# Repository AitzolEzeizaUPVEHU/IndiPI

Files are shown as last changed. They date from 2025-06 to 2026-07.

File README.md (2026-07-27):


# IndiPI
Laboratory kit for Industrial Information Technology based on Raspberry PI 5

## Description
A hands-on educational platform for learning industrial IoT and automation using Raspberry Pi 5.

## Getting Started
The Gerber files are available for creating your own kit. You would need the BOM described, an ADS analog-to-digital converter and a Raspberry PI 5. You can check the figures in order to know how to mount the whole kit.

## Authors
- Imanol Bardaji Zuriarrain
- Aitzol Ezeiza Ramos
- Kauldi Odriozola Ieregi

## License
CC-SA-4.0

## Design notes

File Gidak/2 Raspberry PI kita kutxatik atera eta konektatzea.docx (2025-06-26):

# Raspberry PI kita kutxatik atera eta konektatzea

## Sarrera

Esan bezala, Sistemen ingeniaritza eta Automatika saileko Raspberry PI kitarekin lan egiteko gure laborategietako PCetan software guztia instalatuta aurkituko duzu. Elikatu eta Ethernet kablea ongi konektatzea nahikoa da urrunetik konektatu eta lanean hasteko.

Etxean ere modu berean lan egin nahiko bazenu, gida honek pausoz pauso erakutsiko dizu nola instalatu Ethernet-USB moldagailua Raspberry Piarekin komunikatzeko.

Bi modu ikusiko dugu, bata eskuzkoa, bestea automatikoa. Gure laborategikoa ez den PC batean lan egiteko batzuetan konfigurazio ezberdinak aurkitu ditzakegunez, lehenik eskuzko modua ikusiko dugu eta, horren arabera, agian aldaketa txikiren bat egin beharko diogu tresna automatikoari zure kasuan funtzionatzeko. Aurrera ba!

## Gure kitaren “unboxing”

Gure kitak plaka nagusi bat dauka eta bertan Raspberry Pia jarrita dago, erabiltzeko prest. Funtzionatzeko, ezinbestekoa da elikatzea. Elikatzeko, USB-C kargagailu bat erabiltzen dugu. Edozeinek balio du, baina kitarekin erabiltzen duguna 27 W-ekoa da. Potentzia horrekin, plakak bere ahalmen osoan lan egin dezake. Beraz, lehenengo gauza egin behar duguna elikatzea da (beno, ordenak ez du eragin handirik izango). Ikus 1. Irudia konexioa ikusteko.

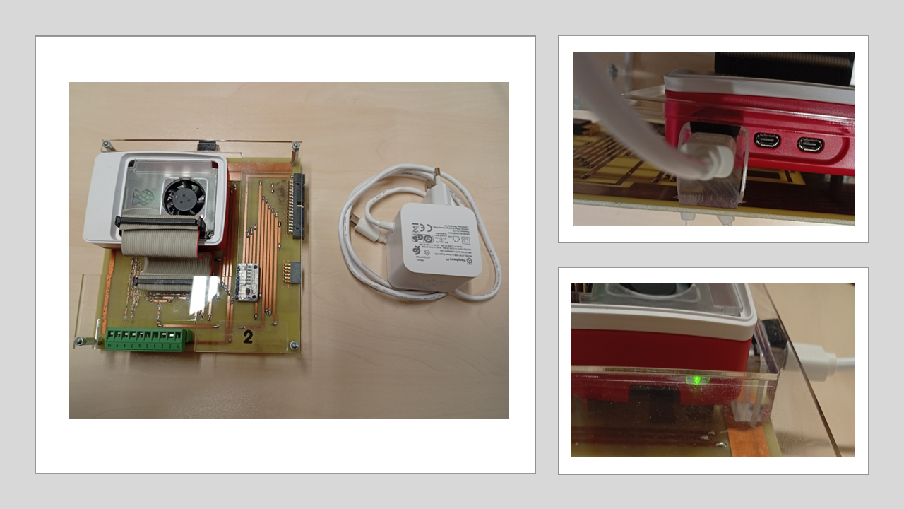
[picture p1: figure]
Raspberry PI kita bere kargagailuarekin.

1. Irudia: Raspberry PI kita bere kargagailuarekin.

Bestalde, Raspberry Piak inora konektatu gabe lan egin badezake ere, gure kasuan PCtik lan egin nahi dugu. Horretarako, Ethernet sarea erabiliko dugu. Gure kasuan, gure laborategiko PCek ez dute WiFirik, beraz, aukera bakarra zen. Etxean WiFia erabil daiteke, baina Raspberry Piaren WiFiak nahiko historia beltza du (gu, behintzat, ez gara gehiegi fidatzen bere WiFiaz). Raspberry Piak RJ45 konektore bat dauka Etherneterako. Guk Ethernet USB moldagailu bat erabiltzen dugu PCra (edo eramangarrira) konektatzeko. 2. Irudian ikus dezakezu nola konektatzen dugun.

Raspberry Piaren kutxan osagai gehiago aurkituko dituzu, baina horiek aurreragorako utziko ditugu. Presarik ez.

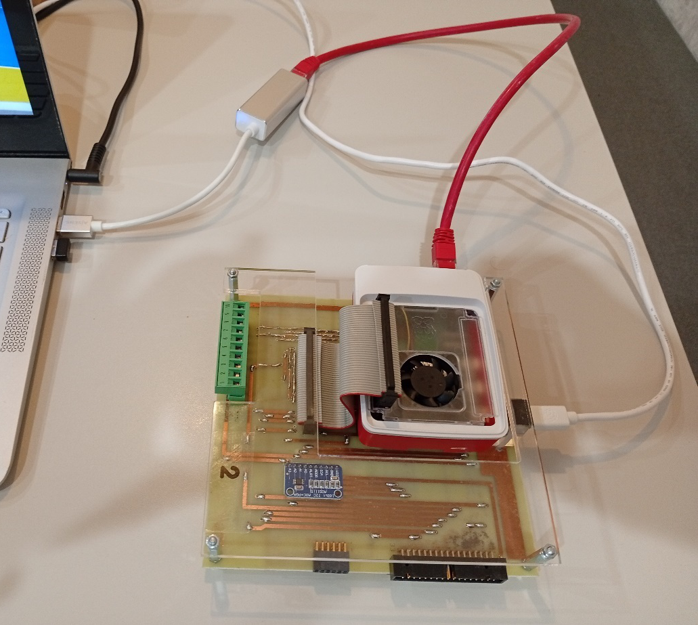
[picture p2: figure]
Raspberry PI Kita elikatuta eta USB moldagailuaren bitartez eramangarrira konektatuta.

2. Irudia: Raspberry PI Kita elikatuta eta USB moldagailuaren bitartez eramangarrira konektatuta.

## Ethernet sarea eskuz konfiguratzen

Windowsen guk erabiltzen dugun Realtek Ethernet USB Gigabit moldagailua automatikoki ezagutzen du. Zoritxarrez, pittin bat latosoa da berarekin lan egitea ez bada ongi konfiguratzen. Guk, gainera, Interneterako sarbidea eman nahi diogu Raspberry Piari gure PCaren bitartez. Interneterako sarbidea zuzenean WiFi bitartez eman daiteke, baina aipatu dugu gure laborategietan zailtasunak ditugula WiFiarekin lan egiteko eta, gainera, Raspberry Piaren WiFia ez da orain arte oso fidagarria izan. Zer egin orduan?

Windowsek Internet Connection Sharing (ICS) izeneko zerbitzu bat dauka, Internetera konektatzeko erabiltzen dugun moldagailuak beste moldagailu bati Interneterako sarbidea emateko. Zerbitzu honekin asko borrokatu behar izan dugu, baina funtzionatzen du ongi konfiguratuz gero. Modu automatikoa gaitzeko aurrerago aipatuko ditugu zailtasunak, baina oraingoz eskuz ongi konfiguratzen saiatuko gara.

Windows 10en, sareen konfigurazioa irekitzeko kontrol paneletik sartu behar dugu (hizkuntzaren arabera ezberdina da (niri adibidez, “Kontrol-panela\Sarea eta Internet\Conexiones de red” agertzen zait, euskara eta gaztelania nahastuz). Edozein hizkuntzatan erraz aurkitzeko modurik onena komando lerroa edo “Exekutatu” leihoa erabiltzea da.

1. Sakatu Win + R teklatuan, "Exekutatu" leihoa irekiko da. Idatzi komando hau eta sakatu Sartu.

control ncpa.cpl

2. Sarea eta partekatzeko zentroa irekitzen da (ikus 3. Irudia).

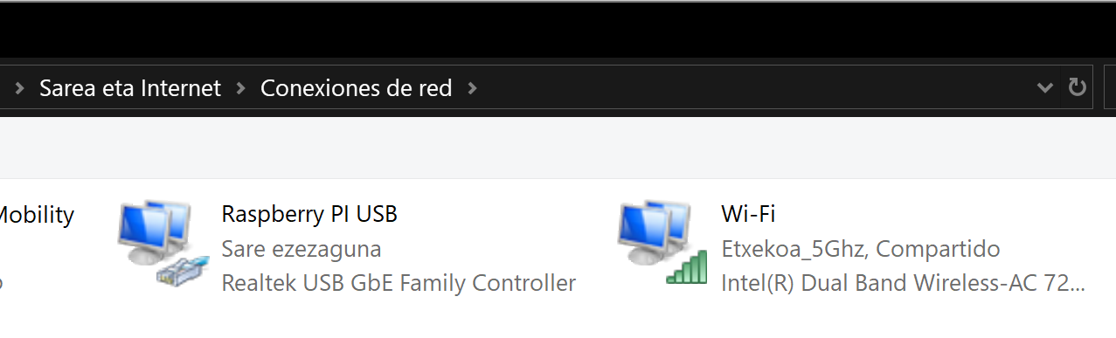
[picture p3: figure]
Sare konexioen kontrol panela.

3. Irudia: Sare konexioen kontrol panela.

3. Internetera sarbidea duen sarea identifikatu. “Ethernet n” izeneko gailu bat ikusten baduzu, begiratu ea Raspberry Pia konektatzeko moldagailua den. Fisikoki deskonektatu eta konektatu egin dezakezu, ikusteko hori dela. Nahi baduzu, izena alda iezaiozu irudian egin dugun bezala, hobeto identifikatzeko.
4. Batzuetan, gailu gehiago izango ditugu, hardwarezkoak edo birtualak. Ez da ezer gertatzen, soilik fijatu zaitez ea horietako baten batek deskribapenean USB edo antzerako zerbait daukan. Automatizatzeko garrantzitsua izan daiteke.
5. Internet eskaintzen duen moldagailua etxeko PC batean Wi-Fi moldagailua izango da ziurrenik. Bere menua ireki dezakezu klik bikoitza eginez. Bertan Propietateak ireki eta “Uso Compartido” atalera joan. Bertan partekatzea aktibatu eta, bi moldagailu baino gehiago badaukazu, Raspberry Piaren moldagailua aukeratu zerrendatik. Gogoratu hau dena Raspberry Pia konektatuta egitea komeni dela (4. Irudia).

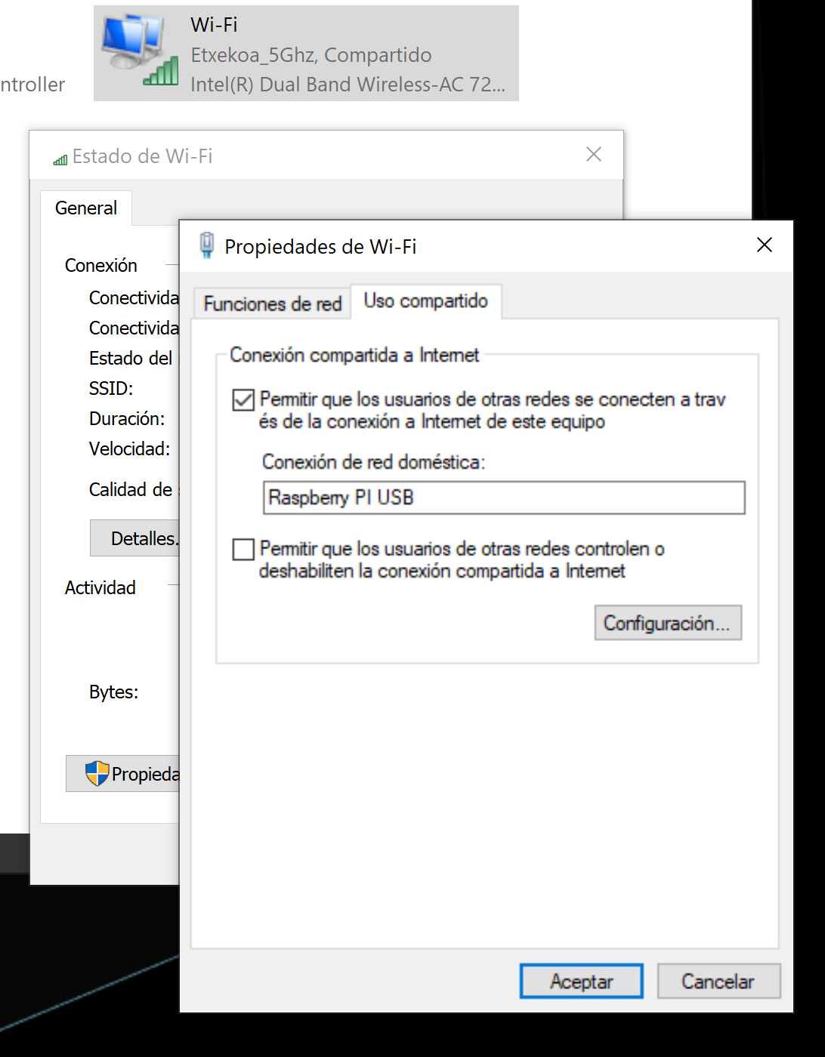
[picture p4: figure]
“Uso Compartido” leihoan egin behar den konfigurazioa.

4. Irudia: “Uso Compartido” leihoan egin behar den konfigurazioa.

6. Behin aktibatuta, zoritxarrez ez du beti funtzionatzen. Gehienetan Raspberry Piaren moldagailua desaktibatu behar da eta berriz aktibatu. Hau oso erraz egiten da “Conexiones de Red” panel horretatik. Hau egitean, IP helbide dinamiko bat esleituko zaio Raspberry Piari eta izen berdina emango zaio beti: raspberrypi.mshome.net (mshome.net atzizkiak sare lokal partekatua adierazten du Windowsen).
7. Amaitzeko, ondo funtzionatzen duen probatuko dugu. Modu errazena TigerVNC erabiltzea da (ikus 5. Irudia). TigerVNC ireki eta x. irudian agertzen den izena jarri. Erabiltzailea eskatzen dizunean, ”pi” jarri eta pasahitza “automatika2024”.

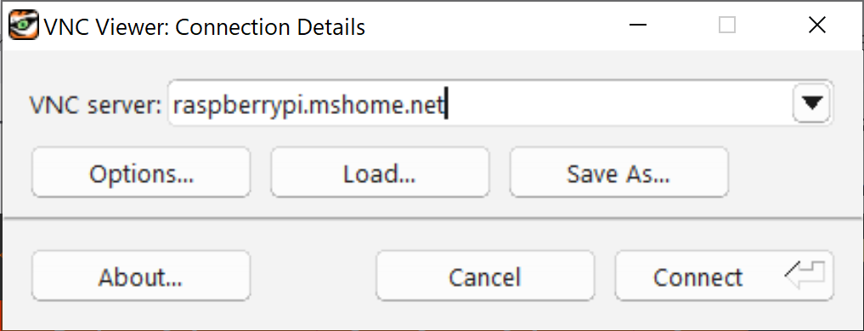
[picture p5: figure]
Tiger VNC konektatzeko prest

5. Irudia: Tiger VNC konektatzeko prest.

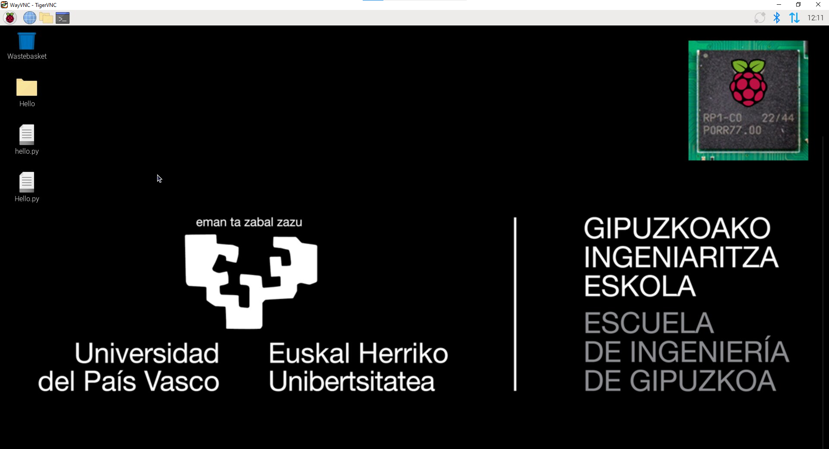
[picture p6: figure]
Raspberry PIaren mahaigaina, TigerVNCtik ikusita.

6. Irudia: Raspberry PIaren mahaigaina, TigerVNCtik ikusita.

Dena ondo badoa, 6. Irudia ikusiko dugu. Zorionak! Errazagoa da esatea egitea baino.

Badago trikimailu aurreratu bat erabiltzailea eta pasahitza ez sartu behar izateko TigerVNC. Aurrerago, berdina egingo dugu VS Coden. PowerShellen agindu hauek funtzionatzen dute:

[System.Environment]::SetEnvironmentVariable('VNC_USERNAME', 'pi', [System.EnvironmentVariableTarget]::User)

[System.Environment]::SetEnvironmentVariable('VNC_PASSWORD', 'xxxxxxxxxxxx', [System.EnvironmentVariableTarget]::User)

## Ethernet sarea modu automatikoan konfiguratzeko scripta

Automatikoki martxan jartzeko aukera guretzat oso interesgarria da. Batetik, eskuz egindako pausoak behin eta berriz egitea aspergarria da. Bestetik, kit ezberdinak PC berdinean erabiliz gero, moldagailua izen ezberdinarekin detektatzen ditu eta pauso guztiak errepikatzeko beharrean gaude. Modu automatikoa aktibatzeko hiru pauso eman behar ditugu.

1. Behar ditugun tresna batzuk instalatu batch script bat erabiliz
2. Konfiguratzeko PowerShell scripta instalatu eta probatu.
3. Ataza programatu bat sortu automatikoki moldagailua konektatzean gure scripta aktibatzeko.

Bide batez, oso interesgarria da gaur egungo ingeniarientzat komando lerroa erabiltzen ikastea eta PowerShell eta antzerako scriptak erabiltzen jakitea. Guk modu gidatuan egingo dugu eta dena prest dago, baina interesgarria da horrelako tresnak ezagutzea.

### 1. Instalazio scripta (SetupRPIKit2025.bat)

Karpeta berean (berdin du non) gorde SetupRPIKit2025.bat, resetICS.ps1 eta resetICS.log.

Karpeta horretara joan eta eskuineko botoiarekin ireki SetupRPIKit2025.bat eta “Exekutatu Administratzaile gisa” aukeratu. Normalean, etxeko PC batean gure erabiltzaile arruntak administratzaile pribilejioak dauzka, baina pribilejiorik gabe lan egiten du ez badiogu kontrakoa esaten (ikus 7. Irudia).

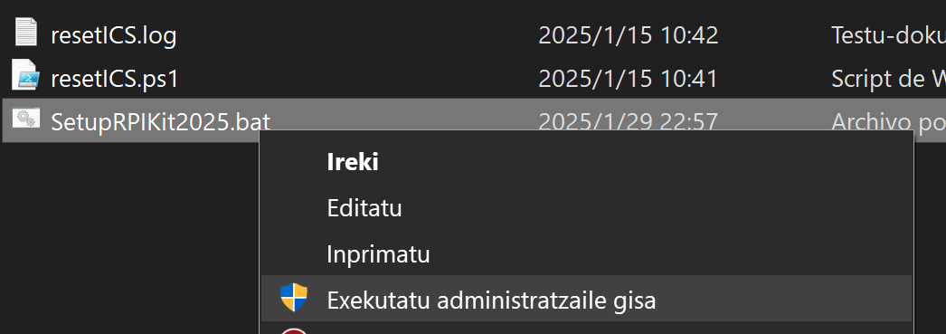
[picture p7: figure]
“Exekutatu Administratzaile gisa” aukera testuinguru menuan

7. Irudia: “Exekutatu Administratzaile gisa” aukera testuinguru menuan

Ongi funtzionatzen badu, C:\Program Files\Scripts karpeta bat sortuko da eta bertara eskuz resetICS.ps1 scripta eta resetICS.log fitxategiak kopiatu behar ditugu.

### 2. PowerShell script nagusia (resetICS.ps1)

Kasu honetan PowerShell script bat exekutatuko dugu, aurrekoa bezala. PowerShell erabiliko dugu, gainera, dena ongi dagoela ikusteko. Ireki PowerShell administratzaile gisa (eskuineko botoiarekin egin dezakezu) eta ondorengo lerroa proba ezazu:

ssh pi@raspberrypi.mshome.net

Agindu honek funtzionatzen badu, pasahitza sartzeko eskatuko dizu (automatika2024) eta dena ongi dago. Segidan, gure scripta ongi dabilen ala ez probatu nahi dugu. Horretarako, Internet Konexioa Partekatzea (ICS) desktibatuko dugu eta ongi desaktibatu den ziurtatu:

disable-ics

eta berriz probatu ssh agindua:

ssh pi@raspberrypi.mshome.net

Orain bai, errorea eman beharko lizuke, hau da, ez luke erantzun behar. Hau gertatzen denean, ez da denbora asko itxaron behar gaizki doala ikusteko. Ctrl+C sakatu prozesuaren iraupena mozteko.

Orain resetICS.ps1 scripta probatuko dugu eta segundo batzuk itxaron berriz saiatu baino lehen. resetICS.ps1 aginduak berak nahita dexente itxaroten du. Ez izan presarik eta amaitzea itxaron ezazu. PowerShell komandoetan itxarotearena Sleep aginduarekin egiten da eta guk geuk ere pausak sar ditzakegu komando lerrotik.

cd “c:\Program Files\Scripts”

resetICS.ps1

Sleep 2

ssh pi@raspberrypi.mshome.net

Bide batez, arrakasta baduzu, Linux sistema eragilearen komando lerroan sartu zara. Zorionak! Oso seinale ona da! Bertatik atera nahi baduzu, “exit” idatzi eta enter saka ezazu. Disable-ScheduledTask errore batzuk ematen badizkizu, lasai, hori fase honetan normala delako. resetICS.ps1 scriptak segundo batzuk beharko ditu, pazientzia izan.

Scripta martxan jarri eta berehala segurtasun ohar bat jasotzen baduzu, hori ere normala da (ikus 8. irudia). “Z” sar ezazu scriptari martxan jartzeko baimena emateko eta lixto.

8. Irudia: Segurtasun oharra PowerShell scripta exekutatzean.

Dena ongi badoa, 9. irudikoaren antzerako zerbait aterako zaizu:

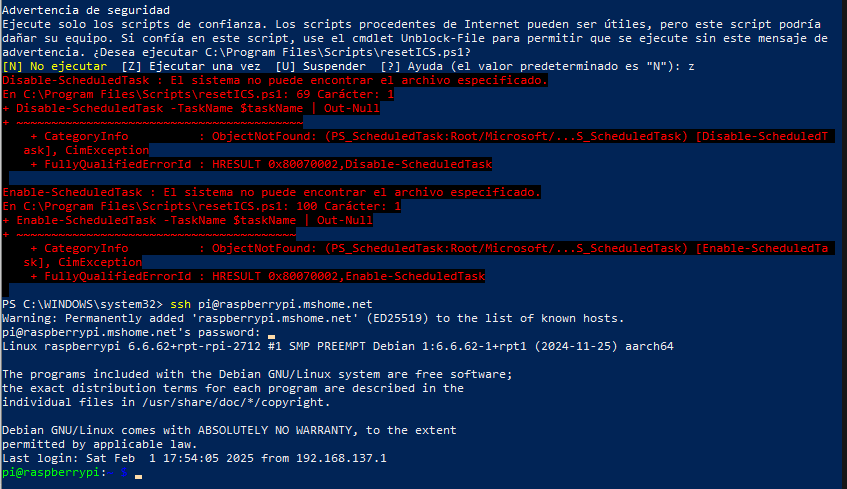
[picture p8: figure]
resetICS.ps1 scripta arrakastaz martxan.

9. Irudia: resetICS.ps1 scripta arrakastaz martxan.

### 3. Ataza Programatua sortzea (RaspberryPIConnect.xml)

Amaitzeko, Ataza Programatzailea (Task Scheduler, Programador de Tareas) erabiliko dugu gure USB portuan moldagailua sartzen dugun bakoitzean gure scripta martxan jartzeko. Hau ere oso interesgarria da berez! Ba al zenekien atazak programatu zitezkeela?

“Programador de Tareas delako bila ezazu Windowseko barran edo, lehen bezala, Windows + R erabili eta hau idatz ezazu:

control schedtasks

Irekiko den tresna oso interesgarria eta aukera ugari ditu. Guk dena prest daukagu dagoeneko, beraz, xehetasun guztiak sartu ordez, prest daukagun ataza inportatuko dugu Acción > Import Task… eginez. (ikus 8. Irudia).

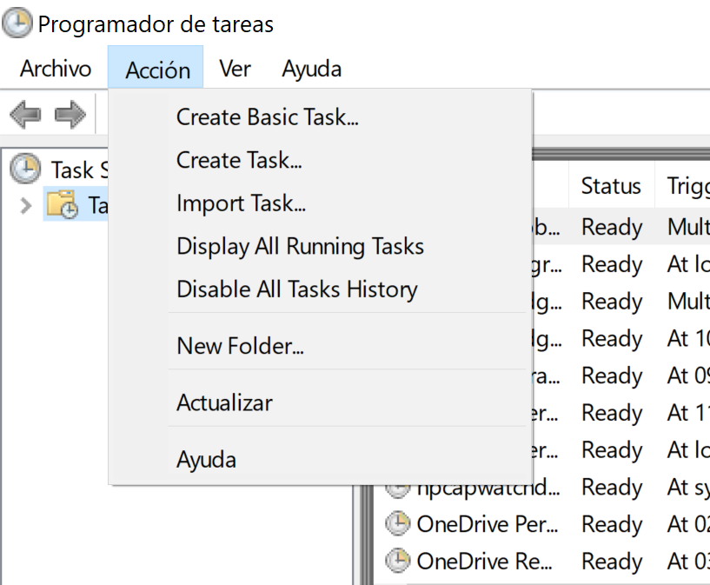
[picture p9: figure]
“Programador de tareas” delakoa. Bertatik “Import Task…” egingo dugu.

10. Irudia: “Programador de tareas” delakoa. Bertatik “Import Task…” egingo dugu.

Hortik aukera ezazu RaspberryPIConnect.xml izeneko fitxategia. Orduan 9. Irudikoaren antzerako agertuko zaizu. Kuriosoa da nola hizkuntzak nahastuta ageri diren. Euskarazko sistemen kasuan, euskara, gaztelania eta ingelesa ager daitezke aldi berean, erokeria da.

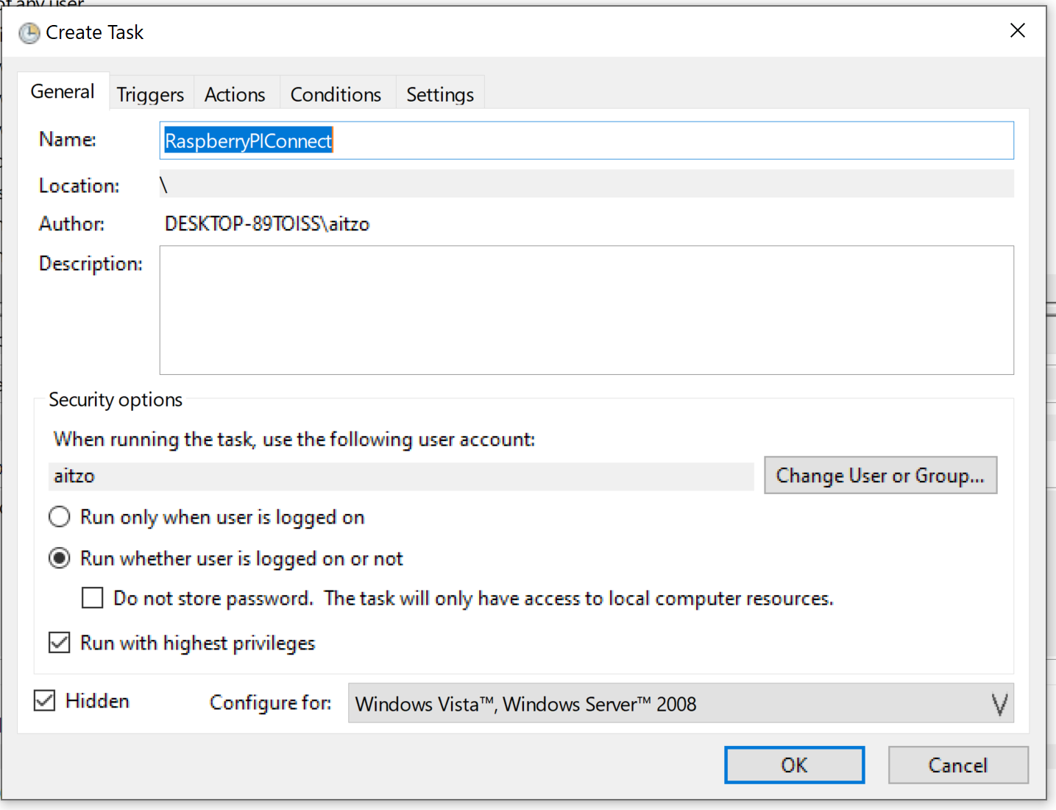
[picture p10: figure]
Create Task leihoa. Bertan ataza programatuaren xehetasunak daude.

11. Irudia: Create Task leihoa. Bertan ataza programatuaren xehetasunak daude.

Oraindik ez dago dena prest, “Change User or Group” botoia sakatu behar delako eta leiho horretan (10. Irudia) zure PCko erabiltzaile izena idatzi eta bilatu beharko duzu. Ez bazaude ziur zein den, zure komando lerroan agindu hau sartu:

whoami

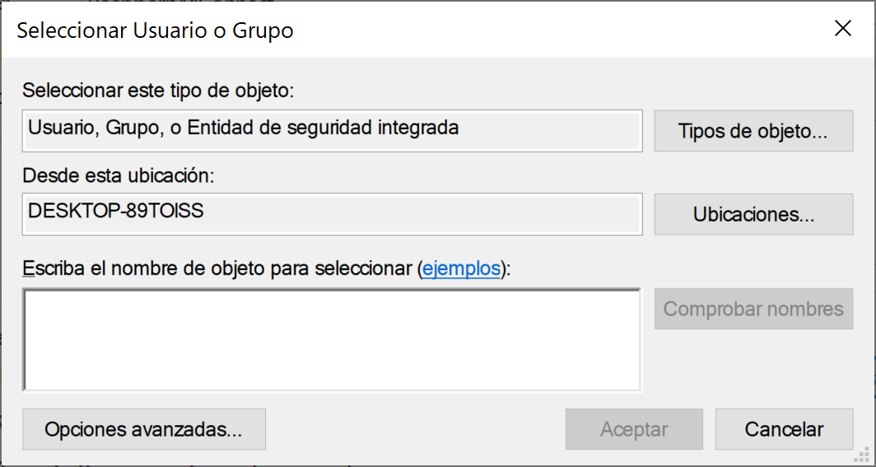
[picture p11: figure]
erabiltzailea aukeratzeko leihoa.

12. Irudia: erabiltzailea aukeratzeko leihoa.

Zure pasahitza eskatuko dizu eta lixto! Dena prest dago. Normalean PIN erabiltzen baduzu, zure erabiltzaile aukeretan pasahitza zein den begiratu beharko duzu.

Ondo dabilela ikusteko, itxi leiho guztiak, deskonektatu zure USB moldagailua, berriz sartu eta probatu (TigerVNC edo komando lerroa, nahi duzuna).

Hurrengo gidan, VS Codetik nola konektatu eta lan egin ikusiko dugu, eta ez baduzu komunikatzea lortu, lasai! Laguntzeko gaude eta, gainera, Troubleshooting gida bat ere irakurri ahalko duzu.

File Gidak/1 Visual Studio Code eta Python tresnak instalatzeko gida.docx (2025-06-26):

# Raspberry PI kitarekin lan egiteko instalazio gida

## Sarrera

Sistemen ingeniaritza eta Automatika saileko Raspberry PI kitarekin lan egiteko gure laborategietako PCetan software guztia instalatuta aurkituko duzu. Etxean ere modu berean lan egin nahiko bazenu, gida honek pausoz pauso erakutsiko dizu nola instalatu dena.

Erabiltzen dugun softwarea doakoa da eta neurri handi batean kode irekikoa. Aukera ugari dago guk laborategian egin nahi duguna egiteko, baina guk erosotasuna eta erabil erraztasuna bilatu ditugu, praktikak arin egin ahal izateko. Instalatuko dugun software guztia ez da beharrezkoa besterik gabe kitarekin lan egiteko, baina ikasketa prozesua aberatsagoa izateko eta askatasun handiagoa emateko gure ikasleei, tresna gehigarri batzuk gehitu ditugu, Raspberry PIarekin egingo ditugun ariketak PCan egindakoekin osatzeko.

## Instalatuko dugun softwarea

- Visual Studio Code: programatzeko tresna.
- Python: programazio hizkuntza, Raspberry Piaren barnean erabiliko dugun berdina.
- TigerVNC: Urrunetik gailu baten mahaigainera konektatzeko doako tresna.
- Ethernet-USB moldagailuarekin erraz lan egiteko scripta.

## Visual Studio Code instalatzea

Visual Studio Code (VS Code) iturburu-kodea editatzeko tresna arin eta indartsua da, Microsoftek garatua da eta mundu osoko garatzaileentzako erreferentziazko tresna bihurtu da. Ez du ia zerikusirik Visual Studio tresnarekin, Microsoften hizkuntza jakin batzuekin programatzeko tresna baita bigarren hau. Gida honetan, Windowsen VS Code nola instalatu ikusiko dugu eta ondoren maiz erabiliko ditugun luzapenak (extension ingelesez) instalatuko ditugu.

### Deskarga eta instalazioa

1. Bisitatu Visual Studio Code web orri ofiziala: https://code.visualstudio.com/

2. Egin klik Windowserako "Download" botoian.

3. Instalatzailea deskargatu ondoren, egin klik bikoitza exekutatzeko.

4. Jarraitu instalazio-morroiaren jarraibideak. Ez ahaztu Add to Path aukeran klik egitea (ikus 1. Irudia)

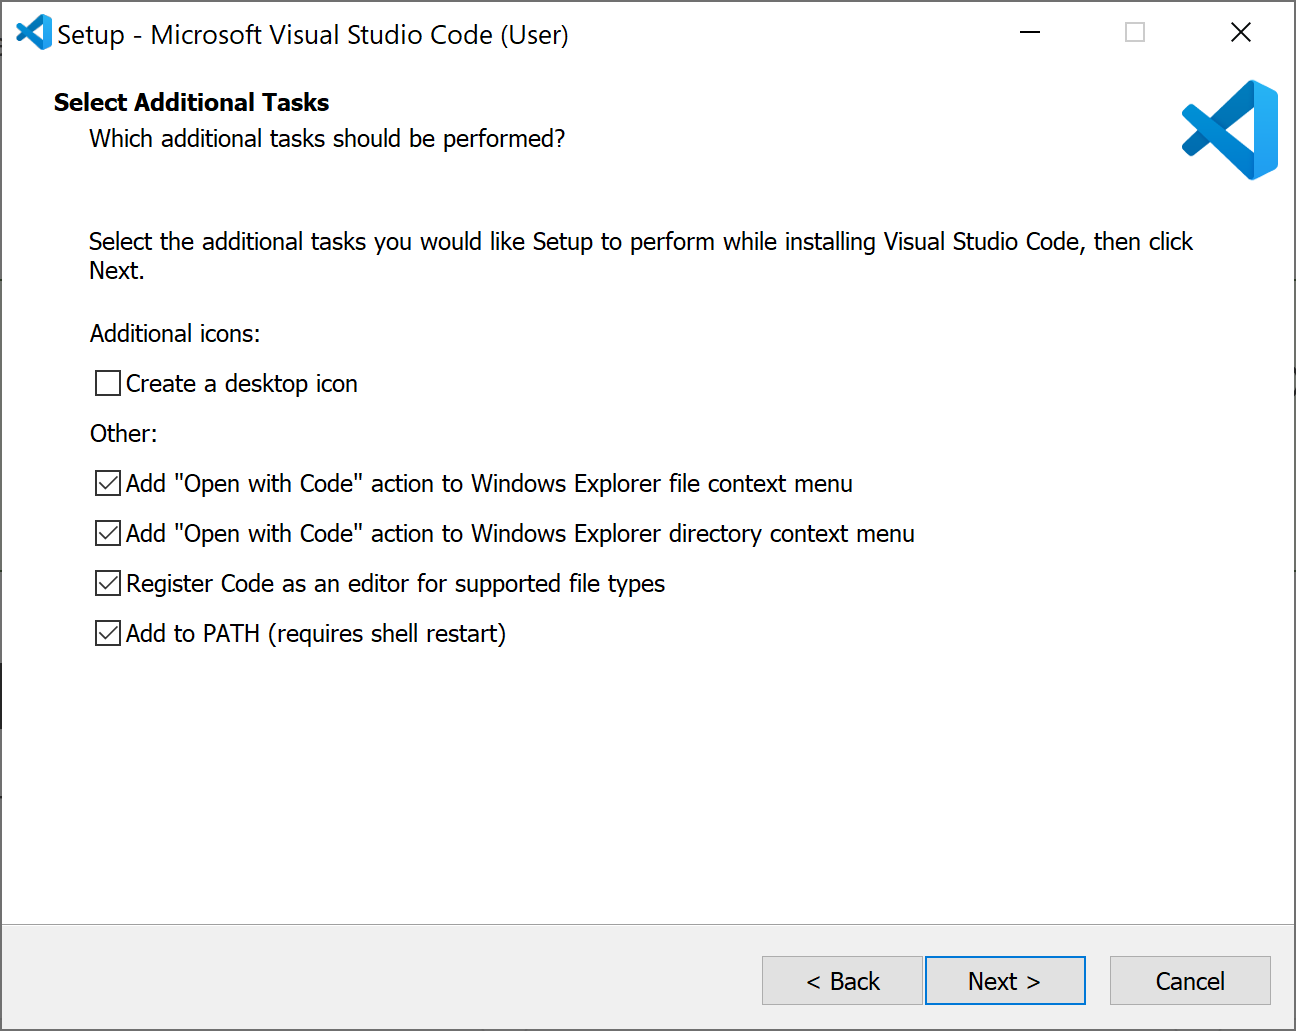
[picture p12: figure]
VS Code instalazioa: ez ahaztu Add to Path aukeran klik egitea.

1. Irudia: VS Code instalazioaren pantaila: gogoratu Add to Path.

## Python.org-etik Python instalatzea

1. Bisitatu Python-en orrialde ofiziala: https://www.python.org/

2. Downloads > Download for Windows menuan egin klik “Python 3.x.x" botoian azken bertsio egonkorra instalatzeko (ikus 2. Irudia).

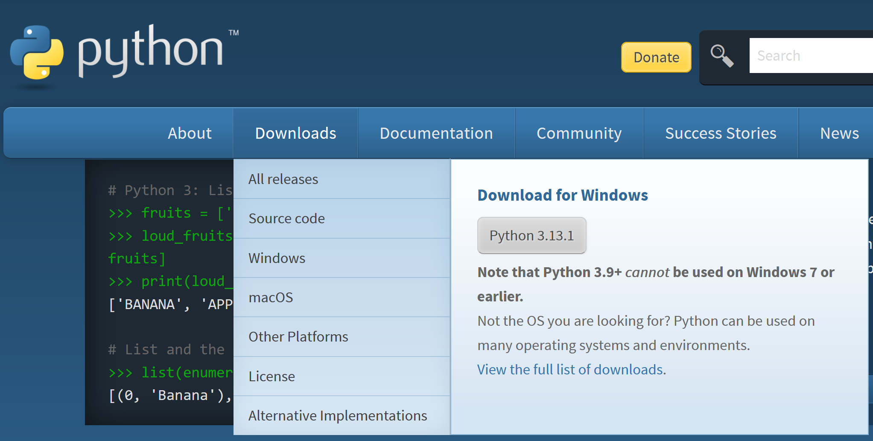
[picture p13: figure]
Python.org orriko instalazio lekua.

2. Irudia: Python.org orriko instalazio lekua.

3. Instalatzailea deskargatu ondoren, egin klik bikoitza exekutatzeko.

4. Markatu "Add Python to PATH" laukia instalatzailearen lehenengo leihoan (ikus 3. Irudia).

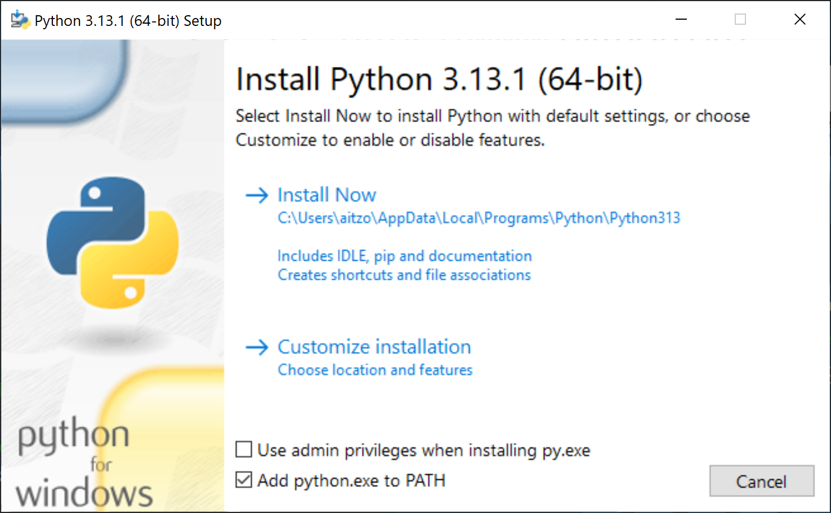
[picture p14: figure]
Python instalatzailea: hemen ere, gogoratu Add to PATH aukera.

3. Irudia: Python instalatzailea: hemen ere, gogoratu Add to PATH aukera.

5. Hautatu "Install Now", ez dugulako ezaugarri berezirik behar (oraingoz) oinarrizko instalazioan.

Azken pausoan (4. Irudia), PATH luzeentzako blokeoa desaktibatzeko eskatzen digu. Hau egitea ideia ona da, batzuetan karpeten antolakuntzaren arabera fitxategien izen osoa oso luzea izan daitekeelako.

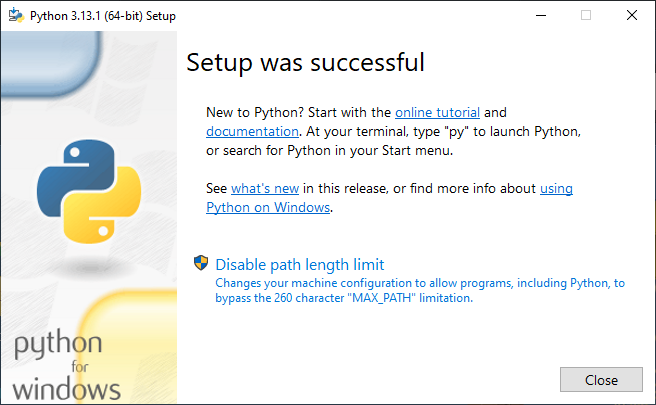
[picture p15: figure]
Instalatzailearen azken orria: PATH luzeetarako aukera aktibatzeko aukera ematen du.

4. Irudia: Instalatzailearen azken orria: PATH luzeetarako aukera aktibatzeko aukera ematen du.

Behin Python instalatuta, normalean komando lerrotik instalatzen ditugu behar ditugun tresna guztiak. Aukera asko egonda ere, hasiera batean pip erabiliko dugu instalazio tresna bezala eta aurrerago uv erabiliko dugu. Ondorengoak izango lirateke behar izango ditugun liburutegiak.

pip install pip-tools setuptools uv ruff pytest requests httpx matplotlib pandas flask

Berriz ere, hauek guztiak ez ditugu behar, baina interesgarriak izan daitezke Python ariketak egiteko PCan (laborategian eta etxean). Windows PowerShell tresnatik agindua sartuta, horrela agertuko litzaiguke (ikus 5. Irudia):

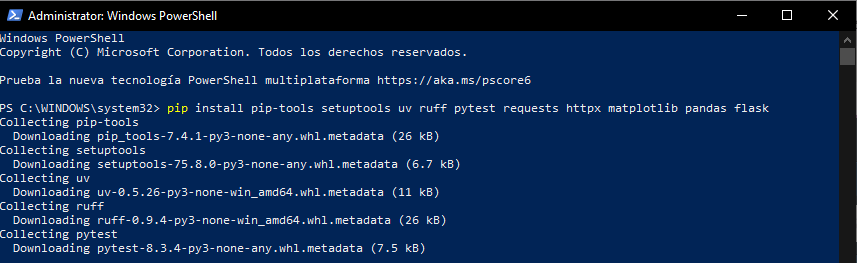
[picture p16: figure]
PowerShell leihoa pip install agindua egitean.

5. Irudia: PowerShell leihoa pip install agindua egitean.

## Python tresnak konfiguratzea VS Coden

### Python luzapenaren (extension) instalazioa

1.Ireki Visual Studio Code.

2. Joan luzapenen sekziora ezkerreko alboko barrako karratuaren ikonoan klik eginez edo Ctrl+Shift+X sakatuz (ikus 6. Irudia).

3. Bilaketa-barran, idatzi "Python" eta hautatu Microsoften luzapena.

4. Klikatu "Install" luzapena instalatzeko.

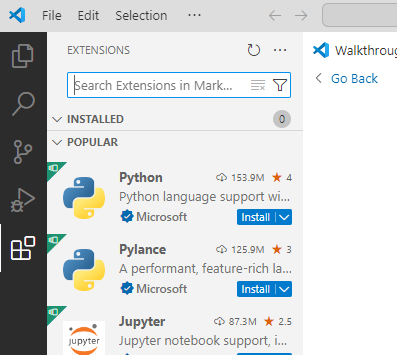
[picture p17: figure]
Extensions menuan klik egitean agertzen dena VS Coden.

6. Irudia: Extensions menuan klik egitean agertzen dena VS Coden.

### Jupyter instalazioa

Jupyter oso tresna interesgarria da, notebook izeneko kontzeptu batean oinarritzen dena. Notebook batean programa baten azalpenak jarri ditzakegu, irudiekin, formulekin… Word sinple batean bezala eta, aldi berean, funtzionatzen duten programa zatiak ere txertatu ditzaket.

1. Luzapenen atal berean, bilatu "Jupyter".

2. Hauta ezazu Microsoften luzapena eta egin klik "Install" botoian.

### Ruff instalazioa

Ruff kodea txukuntzeko tresna da.

1. Bilatu "Ruff" luzapenak bilatzeko barran.

2. Hautatu luzapena eta egin klik "Install" botoian.

### Remote - SSH instalazioa

SSH urruneko gailu batekin modu seguruan konektatzeko oinarrizko tresna da. Windowsen berez badago eta komando-lerrotik (Command Line edo Power Shell) erabil daiteke. Guk gehienetan Visuas Studio Code barrutik erabiliko dugu, Remote SSH luzapena erabiliz.

1. Bilatu "Remote - SSH" luzapenak bilatzeko barran.

2. Hauta ezazu Microsoften luzapena eta egin klik "Install" botoian.

3. Bilatu ere “Remote Development”, urruneko karpetak ere ireki ahal izateko.

3. Aurrerago, Raspberry Pia konektatzean, pauso gehiago eman beharko da (automatikoak dira ia denak) Remote SSH Raspberry PI barruan konfiguratzeko.

## TigerVNC instalatzea

Tresna hau aukerazkoa da, baina instalatuko dugu ere bai. Aukera emango digu urrunetik mahaigaina (Desktop) interfaze grafikoa ikusteko.

1. Bisitatu TigerVNC orrialde ofiziala: https://tigervnc.org/
2. Edo zuzenean deskargatu ondorengo bertsioa: https://sourceforge.net/projects/tigervnc/files/latest/download
3. Bere ikonoa hau da (7. Irudia):

7. Irudia: TigerVNC ikonoa

Eta klik egitean horrela agertuko da (8. Irudia):

Tiger VNC konektatzeko prest

8. Irudia: Tiger VNC konektatzeko prest (raspberrypi… zuk zeuk idatzi behar duzu)

## Ethernet USB moldagailuarekin erraz lan egiteko scripta

Azkenik, Raspberry PI kita konektatu eta martxan ikusi ahal izateko, Windowseko konfigurazioa aldatu behar da. Azken pauso hau egiteko, Raspberry Pia erabili behar denez, bigarren gidan, Raspberry PO kitaren “unboxing”a azaltzen dugun gidan agertuko da azalpena.

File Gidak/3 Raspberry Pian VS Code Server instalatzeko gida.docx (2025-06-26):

# Raspberry Pian VS Code Server instalatzeko gida

## Sarrera

Gure Raspberry PI kita urrunetik programatzeko asmoa dugunez, programatzeko ingurunea moldatu nahi dugu. Horretarako, berriz ere, ez da beharrezkoa VIsual Studio Code erabiltzea (komando lerrotik eta tresna sinpleekin lan egin dezakegu edo, nahi badugu, TigerVNC erabiliz). Gure helburua erosotasuna eta sinpletasuna da eta gure PCaren VS Coden ia oharkabean Raspberry Piarekin lan egin ahal izatea ideia ona iruditzen zaigu.

Visual Studio Codek badu aukera interesgarria urruneko gailu programagarriekin lan egiteko: Visual Studio Coderen “motorra” instalatu daitekeurruneko gailuan eta horrela askoz errazago da lan egitea.

## Visual Studio Code Server instalatzea

Remote SSH luzapena instalatu eta gero, Visual Studio Code irekitzen dugunean ezkerreko barran ikono berria agertzen zaigu eta, gainera, eskuz ssh bitartez konektatu bagara, urruneko konputagailu hori automatikoki agertzen zaigu (ikus 1. Irudia). Hau ez bada agertzen, lasai, ze pauso bat gehiagorekin egin dezakegu dena.

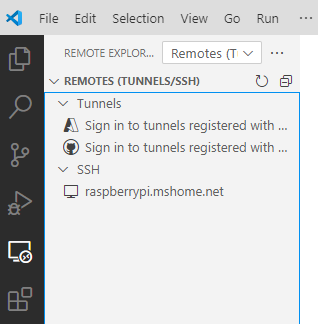
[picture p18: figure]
Remote SSH menu aukera berria.

1. Irudia: Remote SSH menu aukera berria.

Gure kitaren helbidea ez bada agertzen, ssh tresnaren config fitxategia editatu dezakegu edo eskuz gehitu konexioa “Add Remote” botoia sakatuz (ikus 2. Irudia).

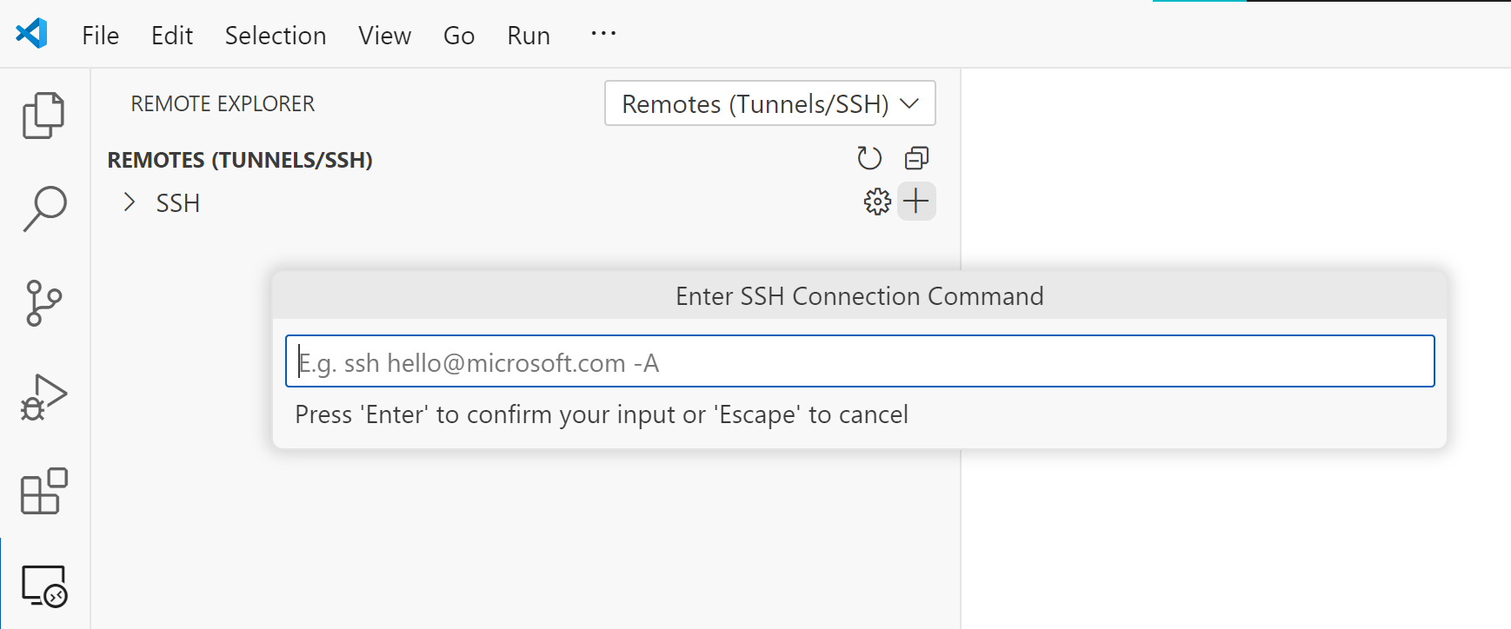
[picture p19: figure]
Add Remote aukera eginez agertzen den menua.

2. Irudia: Add Remote aukera eginez agertzen den menua.

Gure kasuan, gomendatuko dizugu konfigurazioa editatzea, hemendik aurrera konexioek hobeto funtzionatu dezaten. 3. Irudian “Open SSH Config File” ikonoan klik egitean agertzen den aukera daukazu.

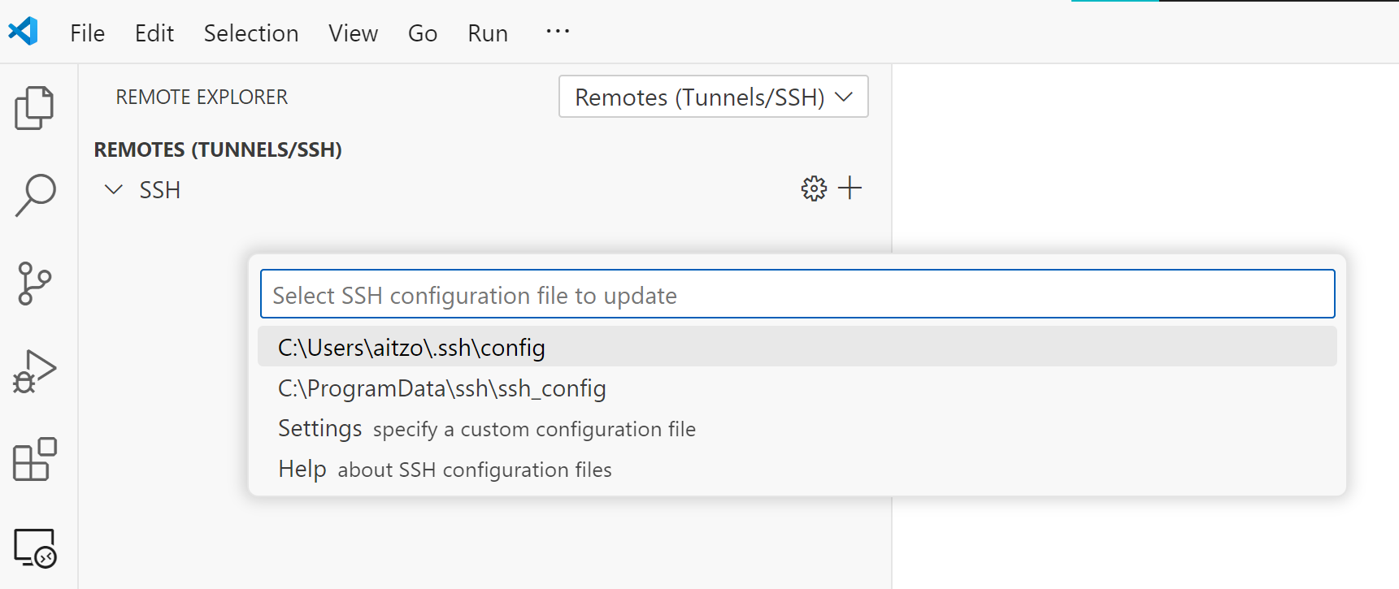
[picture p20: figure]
Open SSH Config File menua: bertan zure erabiltzailearen fitxategia aukera ezazu (irudian "aitzo" agertzen da).

3. Irudia: Open SSH Config File menua: bertan zure erabiltzailearen fitxategia aukera ezazu (irudian "aitzo" agertzen da).

Bertan, zure erabiltzailearen karpetako \.ssh\config fitxategia ireki ezazu eta bertan ondorengo lerroak kopia itzazu. Beste gailu batzuen konfigurazioa badaukazu, utzi bertan. Guk, adibidez, laborategiko PCetan myRIOetara konektatzeko aukerak dauzkagu.

Host raspberrypi.mshome.net

StrictHostKeyChecking no

UserKnownHostsFile /dev/null

User pi

Orain bai, gure raspberrypi.mshome.net gailua irekitzeko klik egingo dugu. Horretarako, aukera ezazu “Connect in Current Window” edo “Open Connection in new Window”, ez du axola. Jarraian, eskatzen dizkigun instalazio pausoei baietz esango diegu. Galdetzen dizunean ea zein motakoa den zure gailua, Linux aukera ezazu, RaspberriOS Linux aldaera bat delako (ikus 4. Irudia).

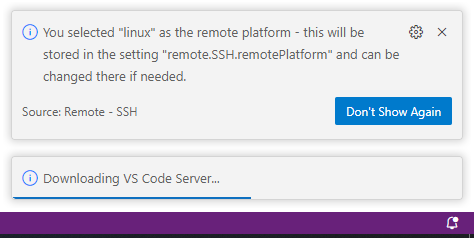
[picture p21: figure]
Linux sistema aukeratzean, Server instalazioari buruzko hainbat galdera agertuko dira.

4. Irudia: Linux sistema aukeratzean, Server instalazioari buruzko hainbat galdera agertuko dira.

Pasahitza ere eskatuko digu (“automatika2024”) eta instalazioa amaitzean, luzapen gomendatuak instalatzeko esango digu. Kasu honetan, eskuz instalatzea ideia hobea da, baina “Show Recommendations” aukera ongi dago (ikus 5. Irudia).

5. Irudia: Luzapenak instalatzeko aukera eskaintza.

Extensions menua bistan daukagula, ikusi dezakegu PCan instalatuta dauzkagun pakete askok “Install Workspace extenion” aukera dutela. Guk honakoak aukeratuko ditugu: Python, Jupyter eta Ruff. Noski, nahi adina instalatu ditzakegu (ikus 6. Irudia).

Azkenik, dena prest dagoenean, instalazioa probatzea gomendatzen dugu, Python ariketa sinpleren bat egiten, baina hau hurrengo gidarako utziko dugu, jada prest gaudelako Python ariketak egiteko. Dagoeneko Python PCan daukagu, kitaren barruan eta kitaren barruan dagoen VS Code Server motorrean ere.

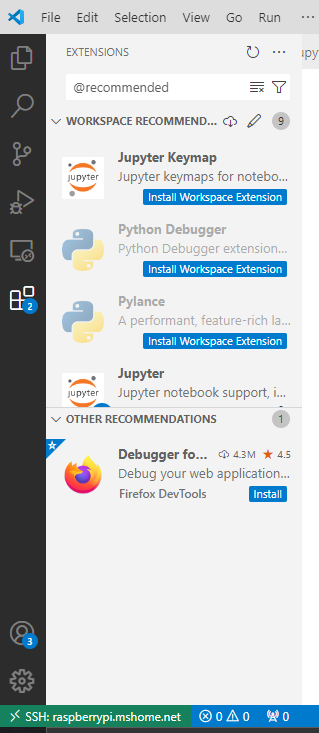
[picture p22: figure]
Extensions menua Remote SSH konexioaren barnean.

6. Irudia: Extensions menua Remote SSH konexioaren barnean.

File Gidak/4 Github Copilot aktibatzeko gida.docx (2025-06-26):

# GitHub Copilot VS Coden aktibatzeko gida

## Sarrera

Gure laborategietan PCa partekatzen dugu eta horrek zailtzen du kontu pertsonalen erabilera tresna integratuetan. Aldiz, etxean edo eramangarrian ez dugu arazo hori izaten eta, beraz, interesgarria da horrelakoak instalatzea, direnak direla. Programatzeko orduan, laguntza ugari dago eta Adimen Aritfizialean (AI, Artificial Intelligence) oinarritzen direnak oso ohikoak dira. Gure konbinazio naturala, VS Code erabiltzean, GitHub Copilot erabiltzea da. Horretarako, GitHub kontua sortu behar da aurretik, baina ikusiko dugunez, hori ere oso interesgarria da guretzako.

## GitHub kontua sortzea

GitHub software garapenean asko erabiltzen den Git bertsioen kontrolerako tresnaren erabilera sustatzeko komunitatea da. GitHuben Hodeiko zerbitzuan gratzaileek bere kodea gordetzen dute, bereziki publikoak izatea nahi dituzten proiektuak, eta Git tresnarekin software horretan egiten diren aldaketak kontrolatzen dira. Gida honetan ez dugu sakonduko horretan, baina jakin ezazu oso interesgarria dela Git erabiltzea eta GitHuben gure ideiak argitaratzea.

GitHub gaur egun Microsoftena da (edo Microsoftek babesten du) eta, horregatik, Copilotekon integrazio oso ona du. Copilot Ai sortzaileko tresna da, Microsoftena, eta M365 lizentzietan sartuta dago (gure unibertsitatean duen lizentzia akademikoa horrelakoa da).

Beraz, lehen pausoan, GitHub kontua sortuko dugu. Ondorengo esteka jarraitu eta sor ezazu doako kontua @ikasle.ehu.eus zure email helbidearekin.

https://GitHub.com/signup

Aktibazio kodea bidaliko dizute emailez eta ongi sartuz gero, 1. Irudiko pantailara helduko zara:

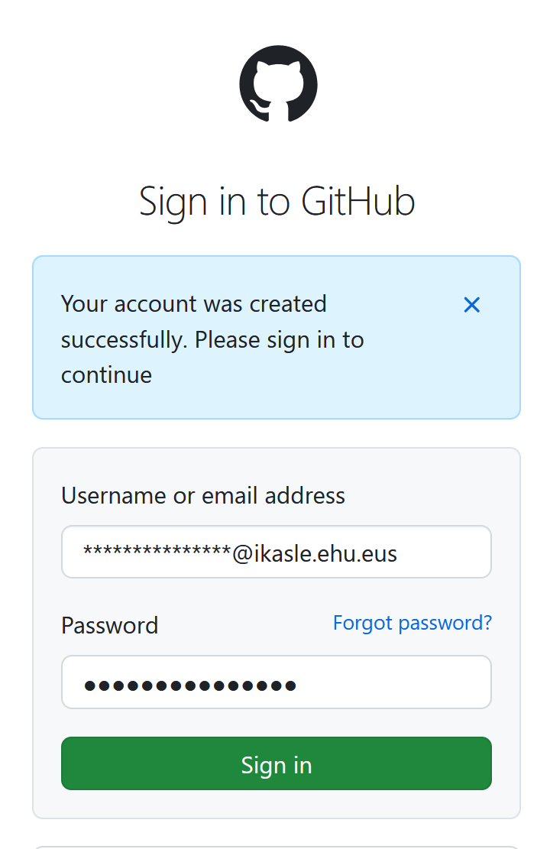
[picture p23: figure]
Github kontua sortzen.

1. Irudia: GitHub kontua sortzen.

Behin barnean sartuta, modu ezberdinak dituzu Copilot aktibatzeko, baina onena hasierako orrian agertzen den ikastaroa jarraitzea da (2. Irudia), pausoak aldatu daitezkeelako gida hau idatzi eta zu sartu bitartean:

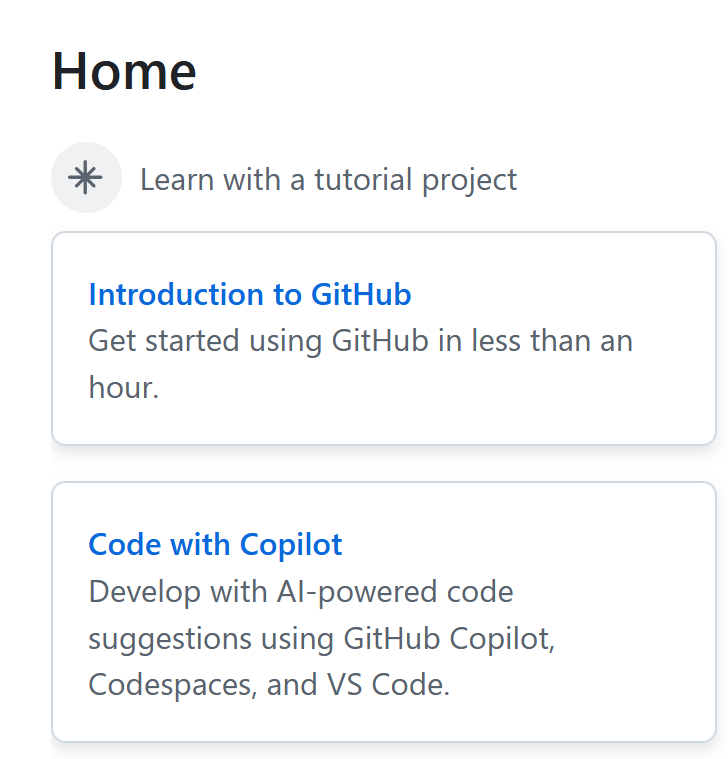
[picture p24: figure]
Code with Copilot ikastaroa Githuben.

2. Irudia: Code with Copilot ikastaroa GitHuben.

## GitHub Pro lortzea ikasle bezala

GitHub doako kontuarekin Copilot erabil daiteke, muga batzuekin. Gure lizentziak aukera ematen duenez, GitHub Pro kontua lor daiteke ikaslea zarela erakusten baduzu. Horretarako, ondorengo estekako pausoak jarraitu behar dira (3. Irudia):

https://education.GitHub.com/discount_requests/application

Github Pro eskuratzeko ikasle bezala.

3. Irudia: GitHub Pro eskuratzeko ikasle bezala.

Application atalean, gure unibertsitatea bila ezazu (ikus 4. Irudia):

Application atalean gure unibertsitatea bilatzen.

4. Irudia: Application atalean gure unibertsitatea bilatzen.

Eta ikasle.ehu.eus helbidearekin hasi bazara, txartela eskaneatzeko eskatuko dizu. Beste helbide bat erabiliz gero, 5. Irudiko mezua agertuko zaizu.

errorea ez bada ikasle kontua erabiltzen.

5. Irudia: errorea ez bada ikasle kontua erabiltzen.

## GitHub Copilot luzapena instalatu eta aktibatzea VS Coden

GitHub Copilot prest dagoenean, VS Coden “GitHub Copilot” luzapena instalatu dezakezu Extensions menutik (ikus 6. Irudia) edo beste modu batzuetara, ondorengo estekak azaltzen duen bezala.

https://code.visualstudio.com/docs/copilot/overview

GitHub Copilot luzapena.

6. Irudia: GitHub Copilot luzapena.

Pausoak jarraituz, zure kontua sar ezazu eta aktibatuta geratuko da. Dena ondo bidean, programatzen hasten zarenean (Python fitxategi bat sortzean, adibidez), Copiloten menua automatikoki agertuko zaizu (ikus 7. Irudia).

Copilot menua: Ctrl+I sakatuz abiarazi daiteke.

7. Irudia: Copilot menua: Ctrl+I sakatuz abiarazi daiteke.

Ariketa bezala, programa sinple bat proposatu dezakezu eta probatu zure PCan, Raspberry Piarekin hasi baino lehen. Informazio gehiago ondorengo estekan:

https://docs.GitHub.com/en/copilot/using-GitHub-copilot/getting-code-suggestions-in-your-ide-with-GitHub-copilot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

Adibidez, eguraldiari buruzko ariketa bat egin daiteke (ikus 8, 9, eta 10. Irudiak).

Ariketaren hasiera: eskaera bat egin Copiloti, ahalik eta zehatzen. Gure adibidean, weather forecast eskatzen diogu.

8. Irudia: Ariketaren hasiera: eskaera bat egin Copiloti, ahalik eta zehatzen.

Copilotek kodea sortzen du eta onartzeko aukera ematen digu.

9. Irudia: Copilotek kodea sortzen du eta onartzeko aukera ematen digu.

Programa onartu eta martxan jartzean, erantzuna ikus dezakegu.

10. Irudia: Programa onartu eta martxan jartzean, erantzuna ikus dezakegu.

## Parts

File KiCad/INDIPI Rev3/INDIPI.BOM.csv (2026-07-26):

Reference | Qty | Value | DNP | Exclude from BOM | Exclude from Board | Footprint | Datasheet
J1 | 1 | ADS1115 |  |  |  | Connector_PinSocket_2.54mm:PinSocket_1x10_P2.54mm_Vertical | ~
J2 | 1 | R PI GPIO 40 |  |  |  | Connector_PinHeader_2.54mm:PinHeader_2x20_P2.54mm_Vertical | ~
J3 | 1 | MXP |  |  |  | Connector_PinHeader_2.54mm:PinHeader_2x17_P2.54mm_Horizontal | ~
J4 | 1 | PMOD |  |  |  | Connector_PinHeader_2.54mm:PinHeader_2x06_P2.54mm_Horizontal | ~
J16 | 1 | Borneroa |  |  |  | Connector_Phoenix_MSTB:PhoenixContact_MSTBVA_2,5_10-G-5,08_1x10_P5.08mm_Vertical | ~

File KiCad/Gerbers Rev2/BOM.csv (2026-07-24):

Id | Identificador | Huella | Cantidad | Identificación | Suministrador y ref
1 | J1 | PinSocket_1x10_P2.54mm_Vertical | 1 | ADS1115
2 | J11,J12,J6,J13,J7,J10,J9,J14,J5,J8 | PinSocket_1x01_P2.54mm_Horizontal | 10 | Conn_01x01
3 | J2 | PinHeader_2x20_P2.54mm_Horizontal | 1 | R PI GPIO 40
4 | J3 | PinSocket_2x17_P2.54mm_Vertical | 1 | MXP
5 | J4 | PinSocket_2x06_P2.54mm_Vertical | 1 | PMOD

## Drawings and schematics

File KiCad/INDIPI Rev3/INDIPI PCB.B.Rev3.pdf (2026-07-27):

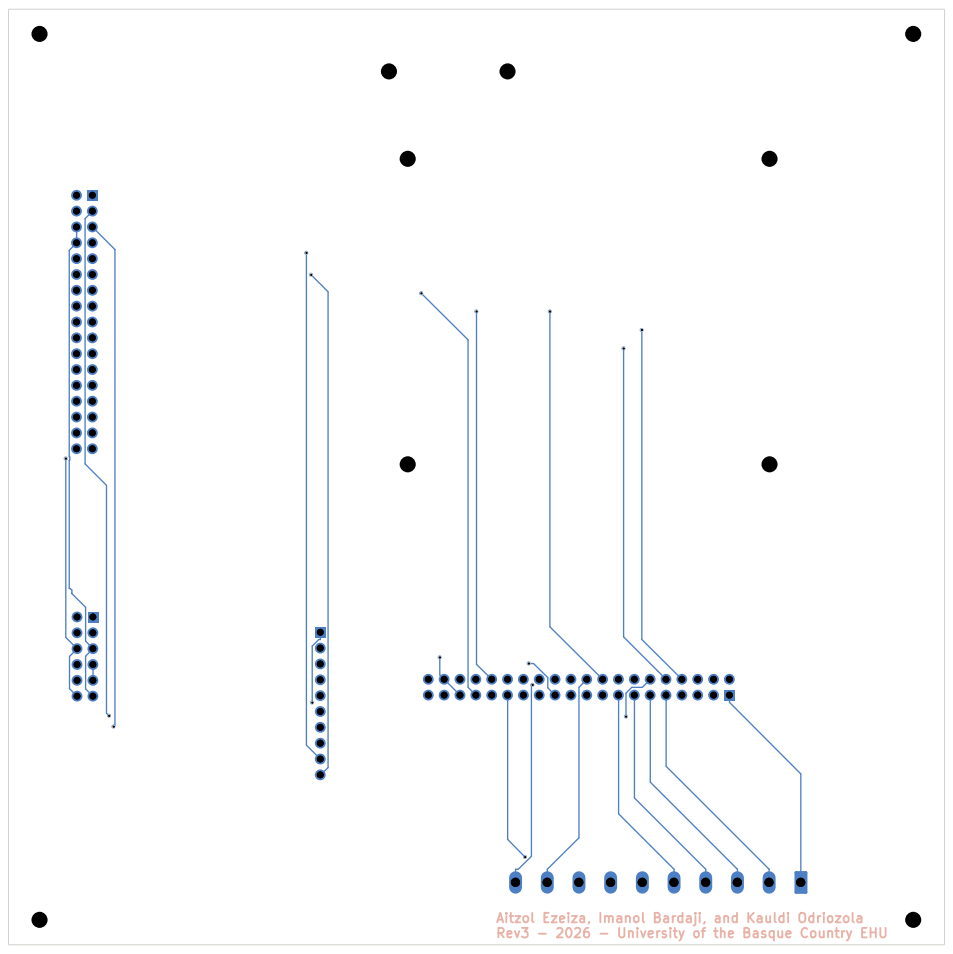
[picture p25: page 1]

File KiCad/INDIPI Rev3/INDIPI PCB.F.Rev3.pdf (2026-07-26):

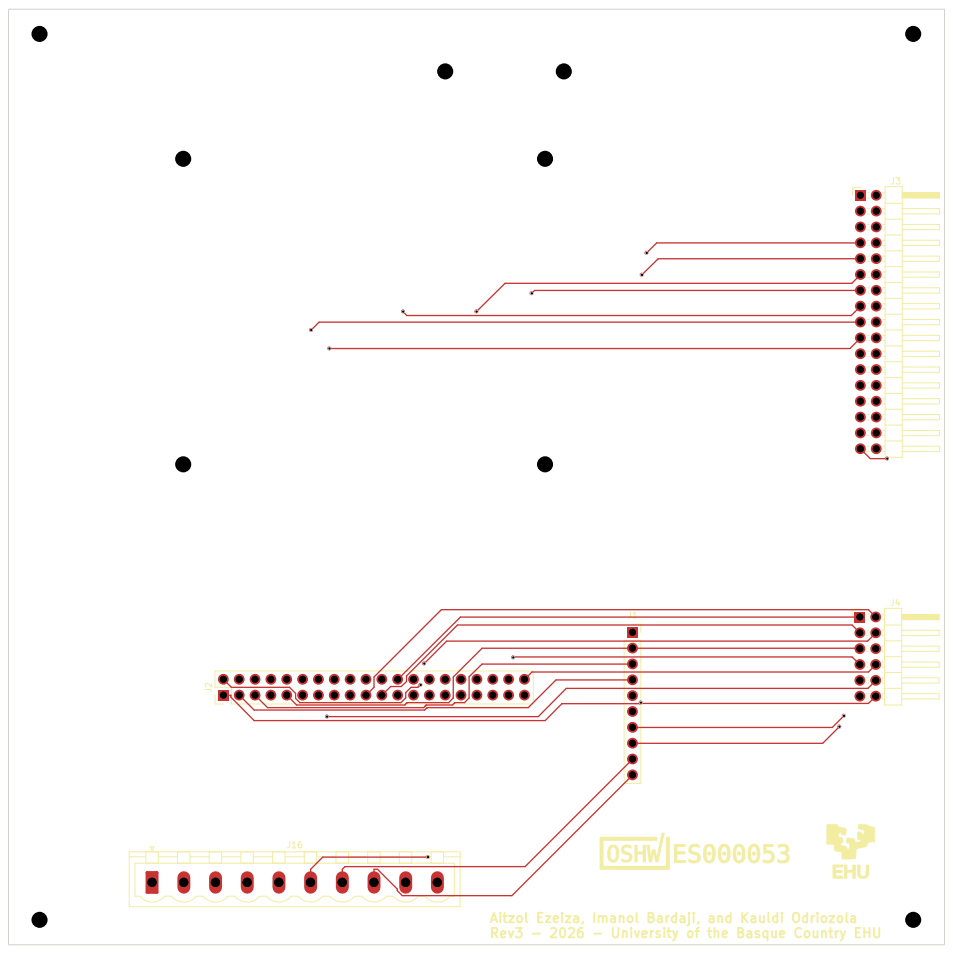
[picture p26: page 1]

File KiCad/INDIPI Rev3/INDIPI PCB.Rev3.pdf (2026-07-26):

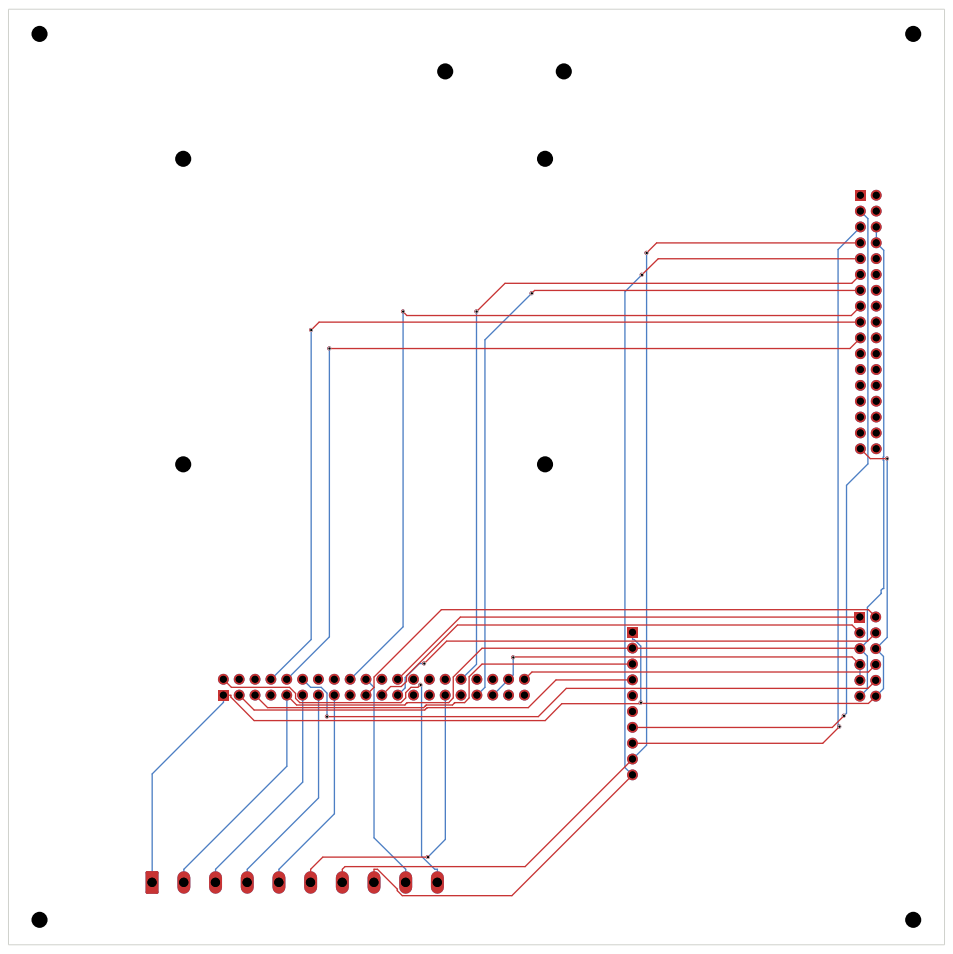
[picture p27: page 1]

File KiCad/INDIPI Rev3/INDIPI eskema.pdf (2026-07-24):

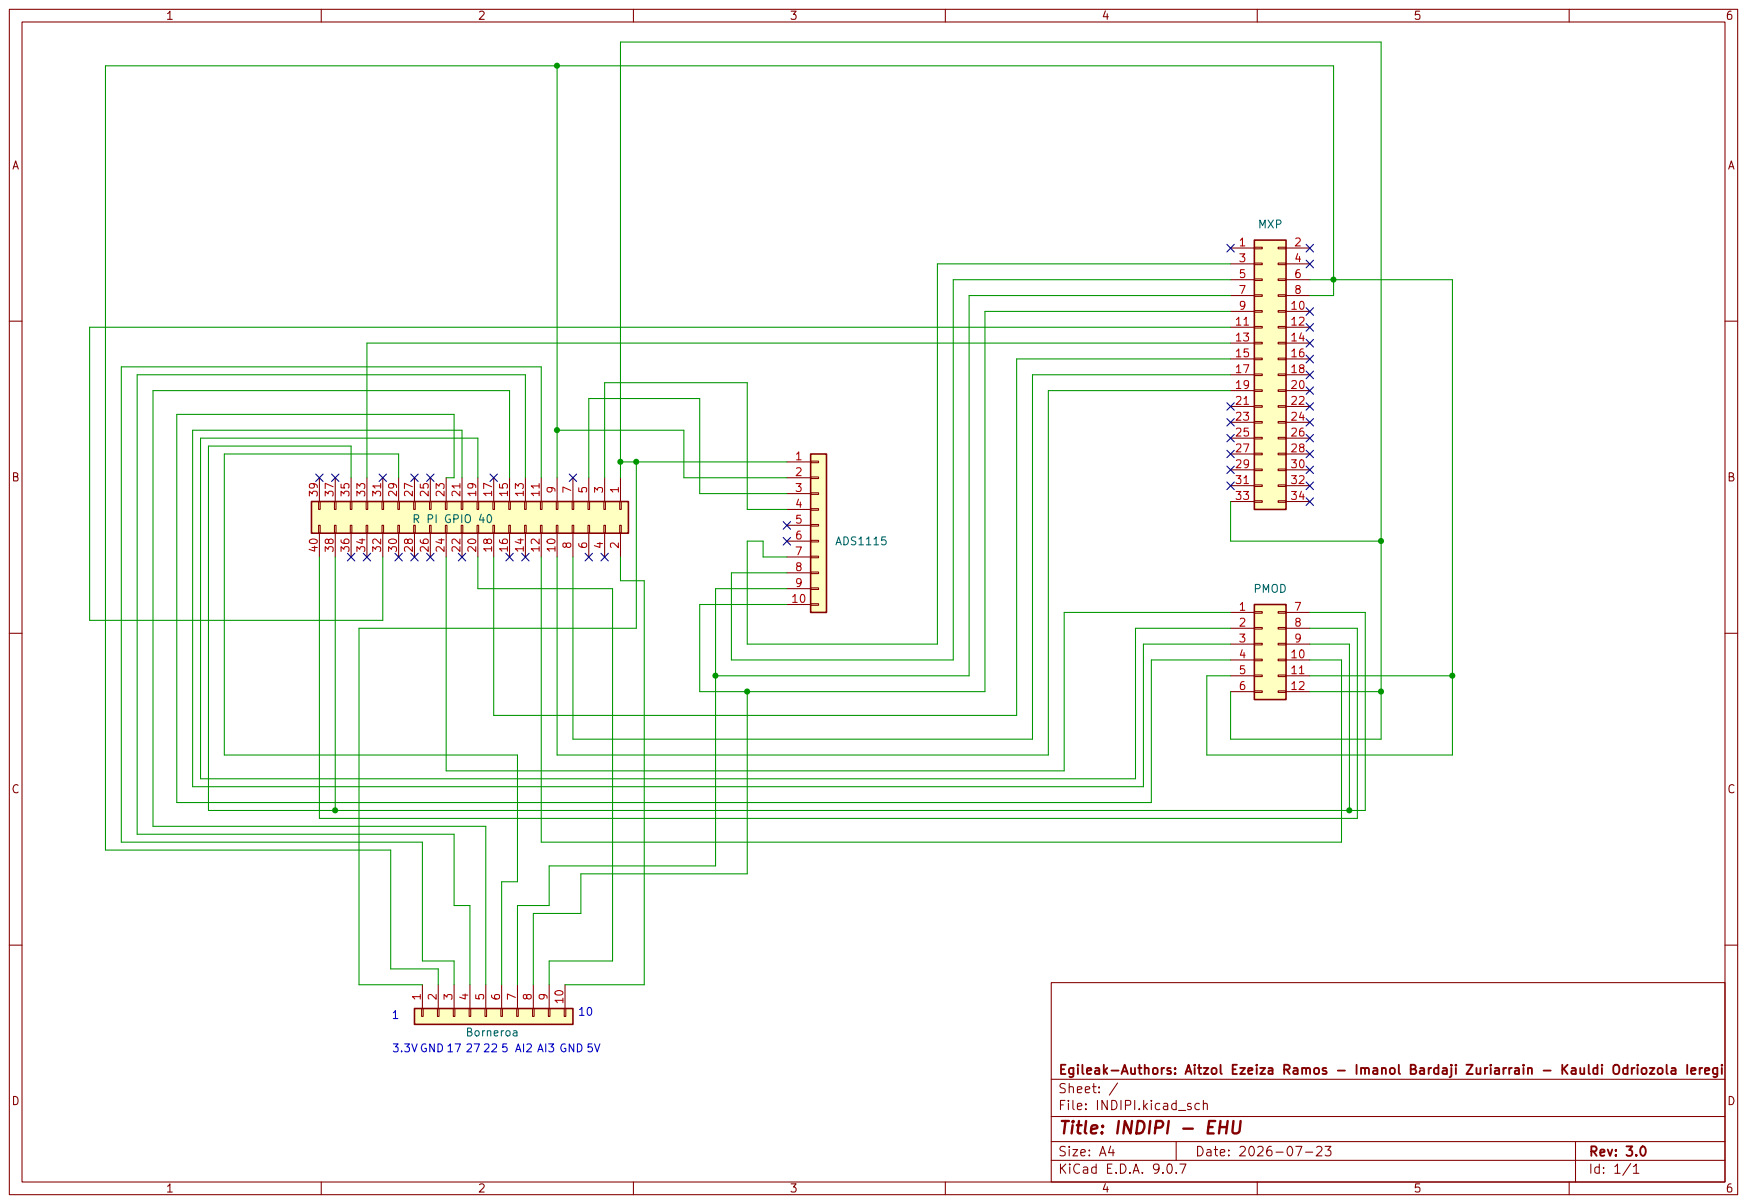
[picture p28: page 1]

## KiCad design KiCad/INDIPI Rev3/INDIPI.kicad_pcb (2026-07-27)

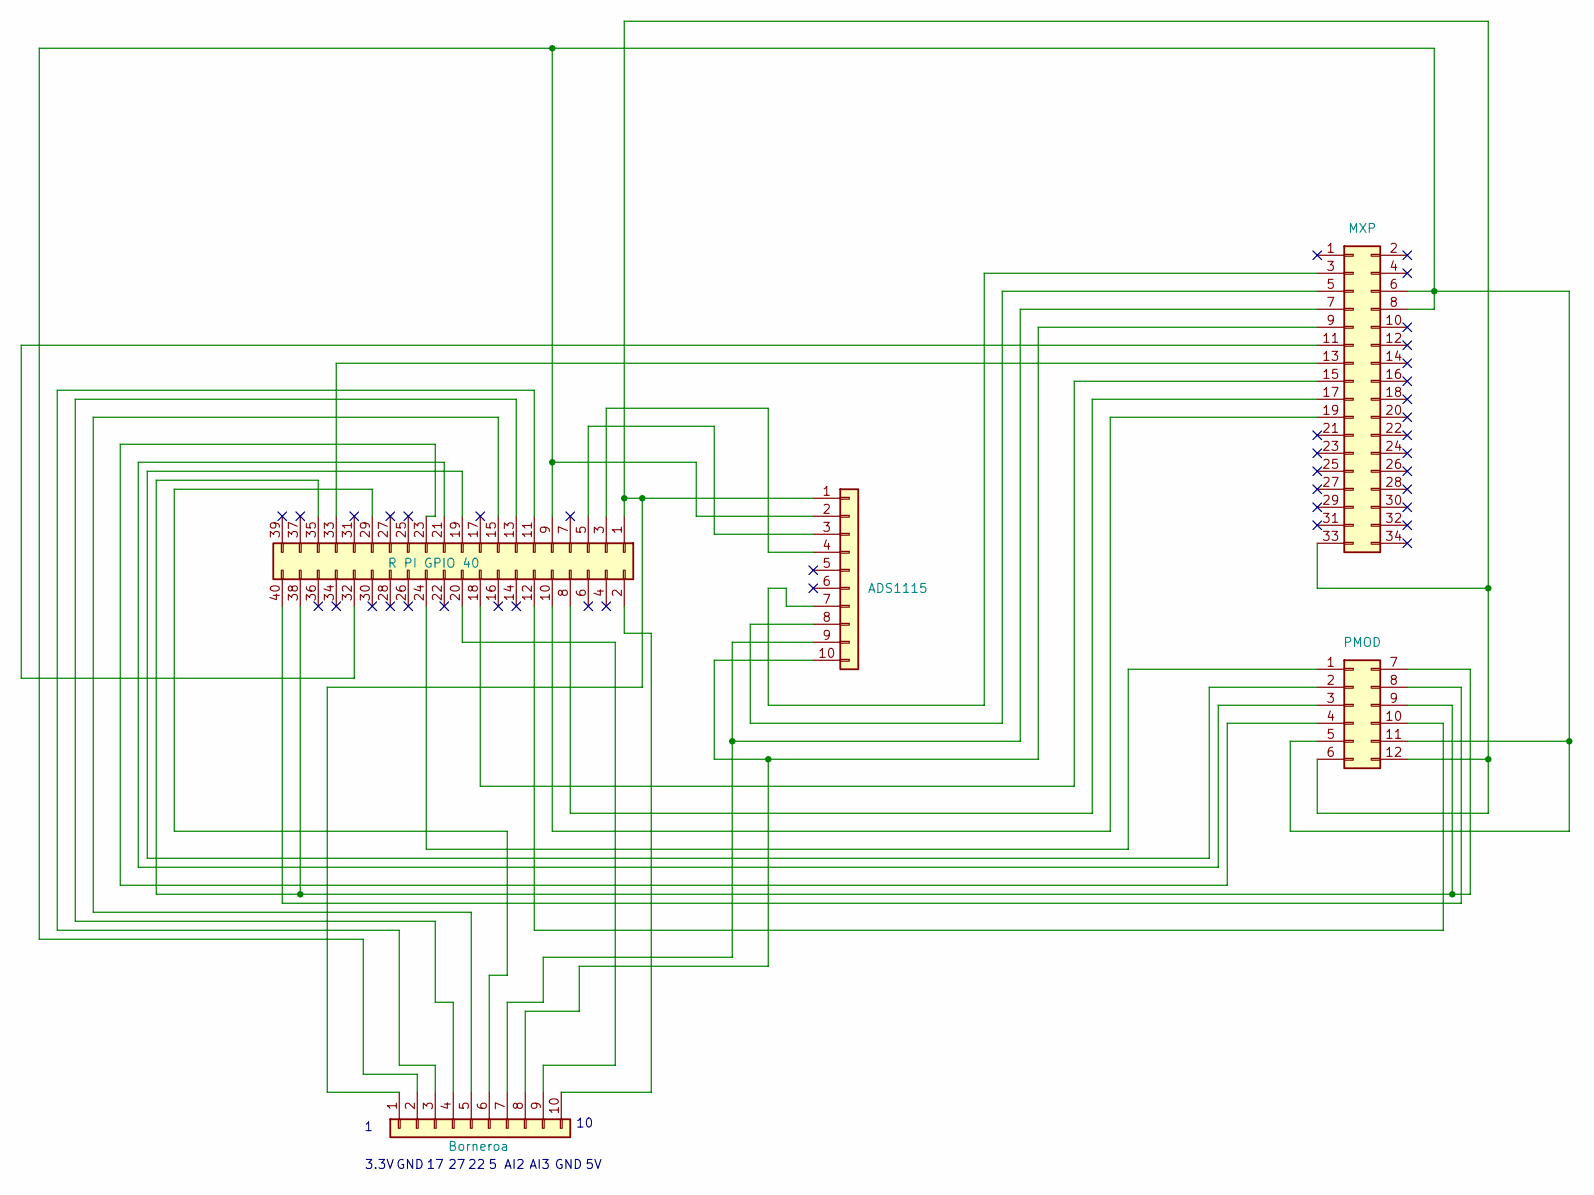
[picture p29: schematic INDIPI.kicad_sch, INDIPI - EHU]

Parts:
J1: ADS1115; PinSocket_1x10_P2.54mm_Vertical
J2: R PI GPIO 40; PinHeader_2x20_P2.54mm_Vertical
J3: MXP; PinHeader_2x17_P2.54mm_Horizontal
J4: PMOD; PinHeader_2x06_P2.54mm_Horizontal
J16: Borneroa; PhoenixContact_MSTBVA_2,5_10-G-5,08_1x10_P5.08mm_Vertical

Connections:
unnamed: J1.1, J2.1, J3.33, J4.6, J4.12, J16.1
unnamed: J1.2, J2.9, J3.6, J3.8, J4.5, J4.11, J16.2
unnamed: J1.3, J2.5
unnamed: J1.4, J2.3
unnamed: J1.7, J3.3
unnamed: J1.8, J3.5
unnamed: J1.9, J3.7, J16.7
unnamed: J1.10, J3.9, J16.8
unnamed: J2.8, J3.17
unnamed: J2.10, J3.19
unnamed: J2.12, J4.10
unnamed: J2.18, J3.15
unnamed: J2.19, J4.2
unnamed: J2.21, J4.3
unnamed: J2.23, J4.4
unnamed: J2.24, J4.1
unnamed: J2.32, J3.11
unnamed: J2.33, J3.13
unnamed: J2.35, J2.38, J4.7, J4.9
unnamed: J2.40, J4.8
unnamed: J2.11, J16.3
unnamed: J2.13, J16.4
unnamed: J2.15, J16.5
unnamed: J2.29, J16.6
unnamed: J2.20, J16.9
unnamed: J2.2, J16.10

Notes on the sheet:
AI2
3.3V
AI3
GND
GND

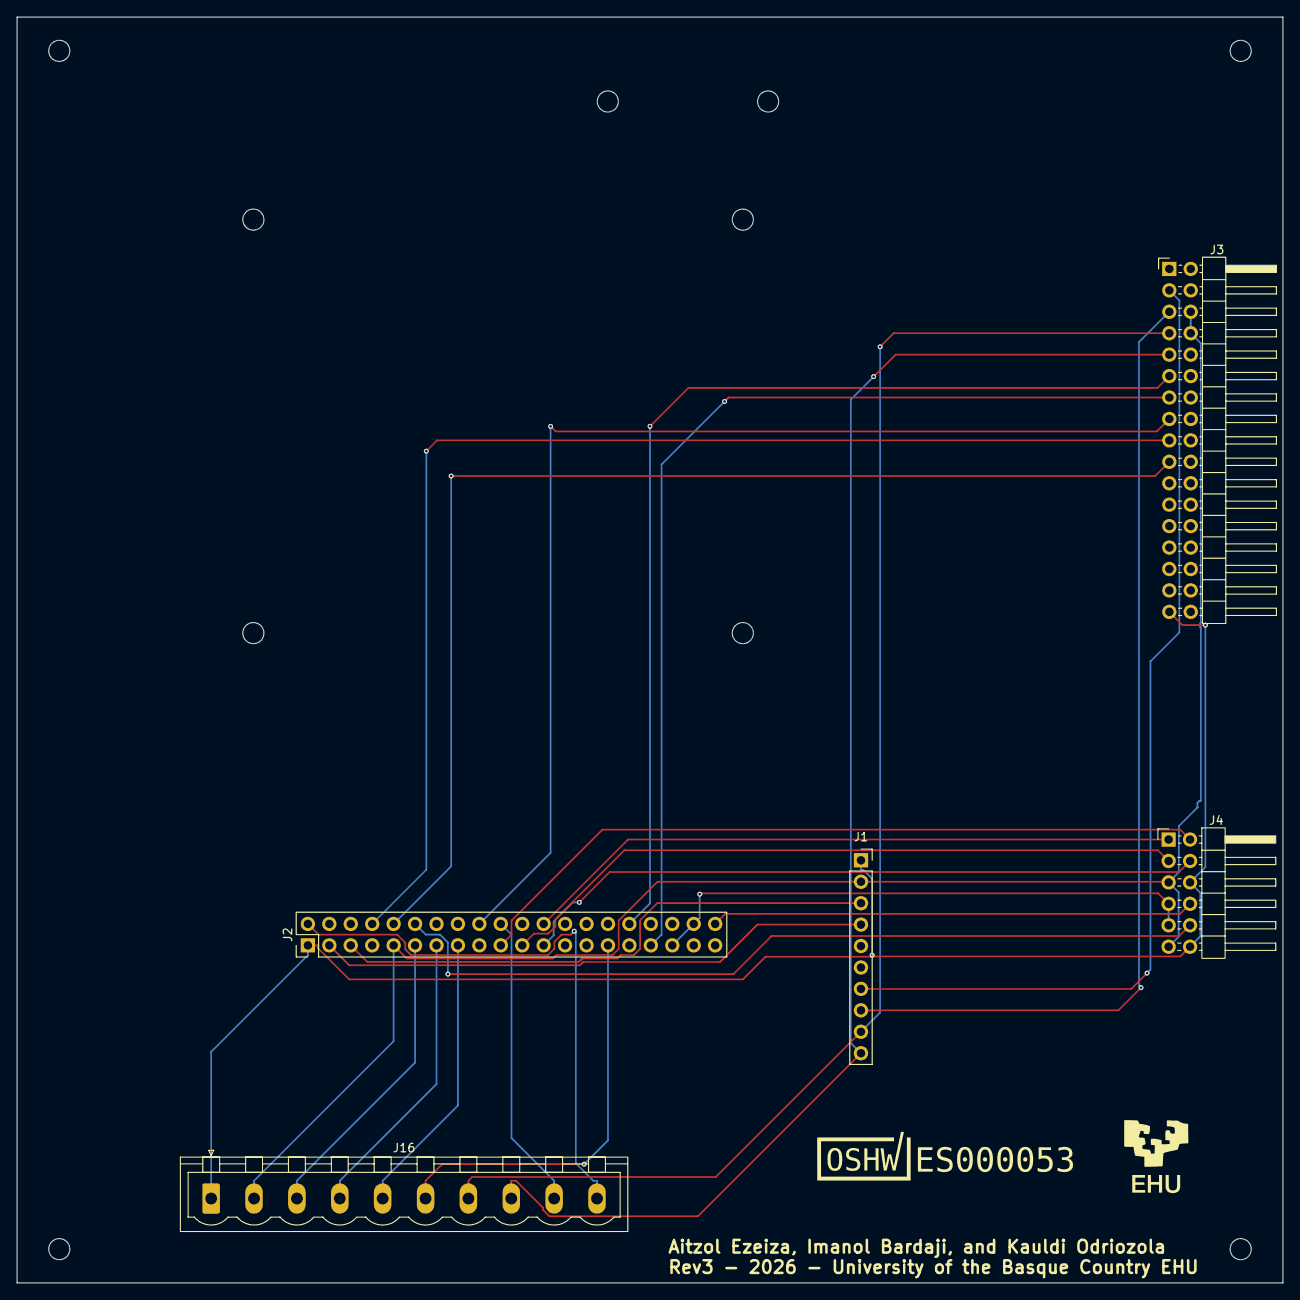
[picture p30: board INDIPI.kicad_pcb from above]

Board: 2 copper layers, 150.0 x 150.0 mm, 17 parts (0 on the bottom side), 26 nets.

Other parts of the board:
EHU: LOGO; EHU_logotipo.txiki
MH1, MH2, MH3, MH4, MH6, MH7: MountingHole_2.5mm
MHR1, MHR2, MHR3, MHR4: MountingHole_2.5mm
OSHWA: LOGO; OSHWA

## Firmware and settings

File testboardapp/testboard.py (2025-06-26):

from flask import Flask, render_template, request, jsonify
from gpiozero import LED, Button
from PMODKYPDTest import PMODKeypad, disable_spi
import Adafruit_ADS1x15
import time


app = Flask(__name__)

adc = Adafruit_ADS1x15.ADS1115(address=0x48, busnum=1)
GAIN = 1
VOLTAGE_RANGE = 4.096
RESOLUTION = VOLTAGE_RANGE / 32768

disable_spi() # Call this function to disable SPI
time.sleep(1)

cols = [11, 9, 10, 8]
rows = [18, 20, 21, 19]
keypad = PMODKeypad(rows, cols)

# Define GPIO pins
output_pins = {
    12: LED(12),
    13: LED(13),
    24: LED(24),
    17: LED(17),
    27: LED(27), 
    22: LED(22),
    5: LED(5),
}

input_pins = {
    14: Button(14),
    15: Button(15)
}


def get_pressed_button():
    key = keypad.get_key()
    if key:
        if key == 'A':
            return 10
        elif key == 'B':
            return 11
        elif key == 'C':
            return 12
        elif key == 'D':
            return 13
        elif key == 'E':
            return 14
        elif key == 'F':
            return 15
        elif key == '0':
            return 16
        else:
            return int(key)
    else:  
        return 0


def get_analog_values():
    values = [0]*4
    for i in range(4):
        # Read the specified ADC channel using the previously set gain value.
        raw_value = adc.read_adc(i, gain=GAIN)
        # Convert raw ADC value to voltage.
        values[i] = raw_value * RESOLUTION
    return {
        "analog0": values[0],  
        "analog1": values[1],  
        "analog2": values[2],  
        "analog3": values[3],
    }

@app.route('/')
def index():
    # Get the state of the input pins
    input_status = {pin: input_pins[pin].is_pressed for pin in input_pins}
    return render_template('index.html', input_status=input_status)

@app.route('/toggle/<int:pin>', methods=['POST'])
def toggle(pin):
    if pin in output_pins:
        output_pins[pin].toggle()
        return jsonify({'status': 'success', 'pin': pin, 'state': output_pins[pin].is_lit})
    return jsonify({'status': 'error', 'message': 'Invalid pin'}), 400

@app.route('/states/<int:pin>', methods=['GET'])
def states(pin):
    if pin in input_pins:
        return jsonify({'status': 'success', 'pin': pin, 'state': "true" if not(input_pins[pin].is_pressed) else "false"}), 200
    return jsonify({'status': 'error', 'message': 'Invalid pin'}), 400

@app.route('/matrix_states', methods=['GET'])
def matrix_states():
    # Initialize the matrix state with all buttons as "Released"
    matrix_state = {f'btn{i}': "Released" for i in range(1, 17)}
    # Get the number of the pressed button (1-16), or 0 if none are pressed
    pressed_button = get_pressed_button()
    # If a button is pressed (not zero), update its status to "Pressed"
    if pressed_button != 0:
        matrix_state[f'btn{pressed_button}'] = "Pressed"    
    # Return the matrix state as JSON
    return jsonify(matrix_state)

@app.route('/analog_values', methods=['GET'])
def analog_values():
    values = get_analog_values()
    return jsonify(values)

if __name__ == '__main__':
    app.run(host='0.0.0.0', port=5000)

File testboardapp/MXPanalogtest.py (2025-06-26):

import time
import Adafruit_ADS1x15

# Create an ADS1115 ADC (16-bit) instance on I2C-1.
adc = Adafruit_ADS1x15.ADS1115(address=0x48, busnum=1)

# Choose a gain of 1 for reading voltages from 0 to 4.09V.
GAIN = 1

# ADS1115 full-scale range for gain=1 is ±4.096V, so the resolution is 4.096V / 32768
VOLTAGE_RANGE = 4.096
RESOLUTION = VOLTAGE_RANGE / 32768

print('Reading ADS1115 values, press Ctrl-C to quit...')
print('| {0:>10} | {1:>10} | {2:>10} | {3:>10} |'.format('Channel 0 (V)', 'Channel 1 (V)', 'Channel 2 (V)', 'Channel 3 (V)'))
print('-' * 49)

# Main loop.
while True:
    # Read all the ADC channel values in a list.
    values = [0]*4
    for i in range(4):
        # Read the specified ADC channel using the previously set gain value.
        raw_value = adc.read_adc(i, gain=GAIN)
        # Convert raw ADC value to voltage.
        values[i] = raw_value * RESOLUTION
    # Print the voltage values.
    print('| {0:>10.4f} | {1:>10.4f} | {2:>10.4f} | {3:>10.4f} |'.format(*values))
    # Pause for one second.
    time.sleep(1)

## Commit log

2026-07-24 Adding Rev3
    [BOM.csv, INDIPI.kicad_pcb, INDIPI.kicad_sch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]
2026-07-24 Rev3 complete revision and Gerbers generated
    [INDIPI-B_Cu.gbr, INDIPI-B_Mask.gbr, INDIPI-B_Paste.gbr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]
2026-07-26 Rev 3.1 - Decorations and hole adjustments
    [INDIPI-B_Cu.gbr, INDIPI-B_Mask.gbr, INDIPI-B_Paste.gbr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]
2026-07-27 Rev3 ready to send
    [INDIPI-B_Cu.gbr, INDIPI-B_Mask.gbr, INDIPI-B_Paste.gbr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]
